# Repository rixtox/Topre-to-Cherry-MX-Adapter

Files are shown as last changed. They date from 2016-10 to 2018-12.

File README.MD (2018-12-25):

# Topre to Cherry MX Adapter

> [][2]
HHKB Topre to Cherry MX Adapters by [Naiwei Zheng][3] is licensed under a [Creative Commons Attribution-NonCommercial-ShareAlike 4.0 International License][2].

This is a 3D printable model made with SolidWorks that works to replace the cylindrical sliders (or plunger) of Topre switches on HHKB. The idea was first come up with Matt3o, and then the NovaTouch implemented the design in their products. For more information you can read [my blog about this project.][4]

This model made several improvements to [Matt3o's beta STL design model][5]. The base stands were made thinner to prevent stucking the rubber dome while pressed. The base was made exactly the same as the original Topre's to retain the touch feeling.

If you want to support this work, you can buy from my [Shapeways shop][6] where I make 10% fixed profits, or you can donate to [my PayPal][7] or BitCoin wallet: 14VSt78bfgMx9pWXV9qbMMsxter7KYHCRd. However you are always welcome to print and use this work for personal use without paying me.

## Compatibility Notes

Since different manufactures may have different specifications in their keycap dimensions, current design may not fit perfectly on every keycap out there. Hence hereby you are welcome to provide any compatibility results to me.

* [The Amazing Chocolatier Custom SA Keycap Set][8] - **Compatible**
* [87U with PuLSE SA Keycap Set][9] - **Wobbly 2.25u** ([Issue #1][10])

## Image Previews

### 1u Standard Adapter

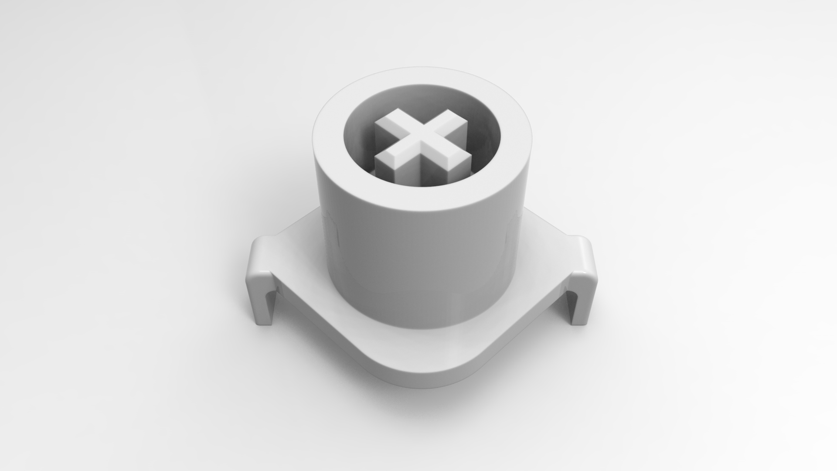
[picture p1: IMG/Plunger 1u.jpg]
Plunger 1u


### 2.25u Left Shift & Enter Adapter

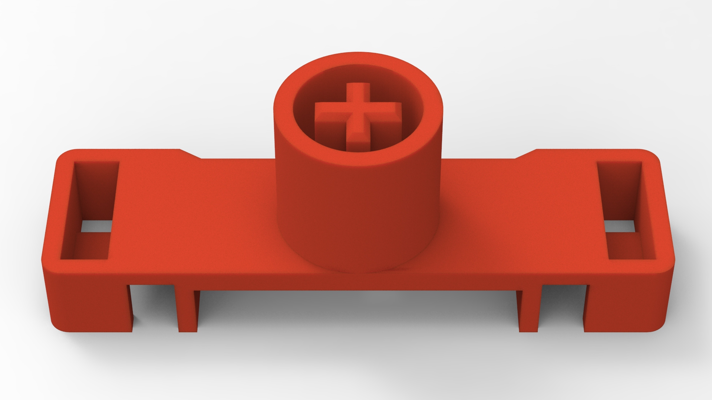
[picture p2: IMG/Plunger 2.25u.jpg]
Plunger 2.25u


### 6.25u MX Spacebar Stabilizer Adapters

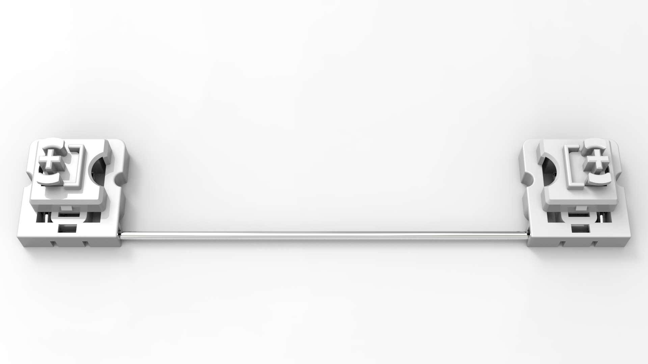
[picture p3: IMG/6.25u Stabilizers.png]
6.25u Spacebar Stabilizers


### 6u MX Spacebar Stabilizer Adapters

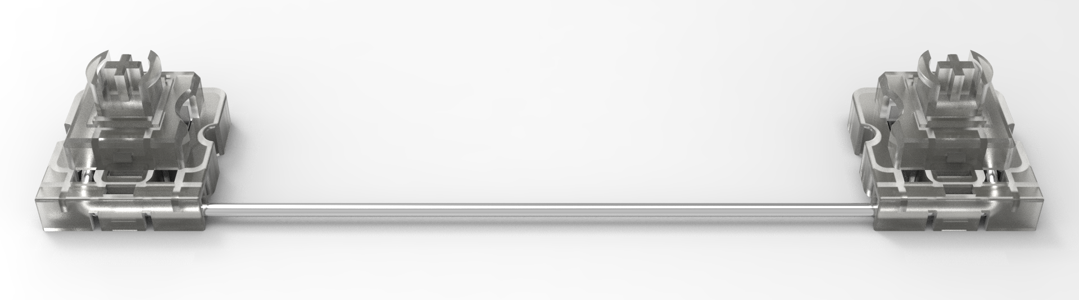
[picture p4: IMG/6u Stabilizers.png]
6u Spacebar Stabilizers


### 6u Topre Spacebar

In case you couldn't buy a PBT Topre 6u spacebar, I also made a model
for you to 3D print it.

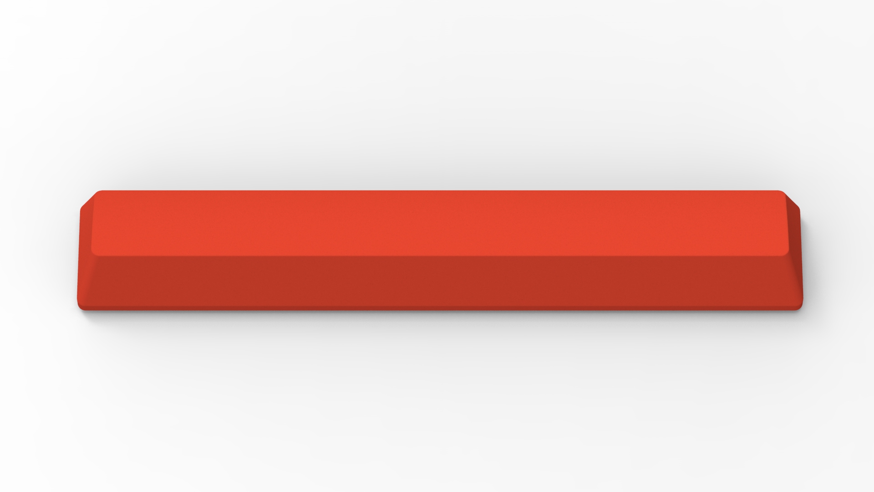
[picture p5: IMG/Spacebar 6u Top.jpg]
Spacebar 6u Top


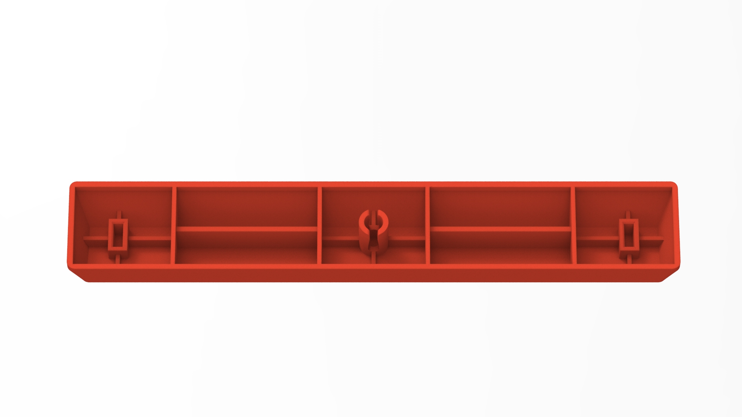
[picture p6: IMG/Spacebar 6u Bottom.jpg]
Spacebar 6u Bottom


## File Structure

    .
    ├── README.MD               # This document
    ├── ASM/                    # Assembly files
    ├── IMG/                    # Preview images
    ├── PRT/                    # Parts files
    └── STL/                    # 3D printable files

[1]: https://i.creativecommons.org/l/by-nc-sa/4.0/88x31.png
[2]: https://creativecommons.org/licenses/by-nc-sa/4.0/
[3]: https://github.com/rixtox/Topre-to-Cherry-MX-Adapter
[4]: https://rix.li/topre-to-cherry-mx-adapter/
[5]: http://matt3o.com/topre-to-cherry-mx-adapter/
[6]: https://www.shapeways.com/shops/axiom-1
[7]: https://paypal.me/naiwei
[8]: https://www.massdrop.com/buy/24022
[9]: https://www.massdrop.com/buy/pulse-sa-keycap-set
[10]: https://github.com/rixtox/Topre-to-Cherry-MX-Adapter/issues/1

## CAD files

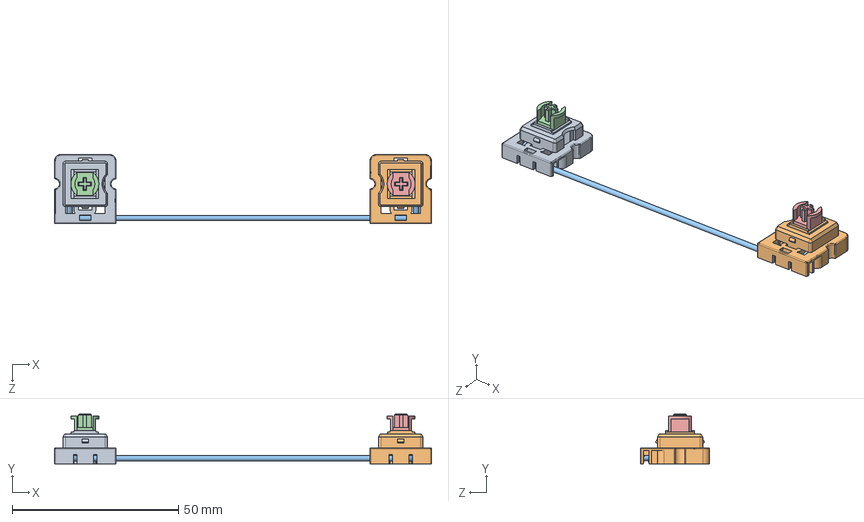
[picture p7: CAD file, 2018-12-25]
ASM/6u Stabilizers.SLDASM
113.5 x 14.9 x 20.9 mm
6u Stabilizer Housing Left
6u Stabilizer Housing Right
Stabilizer Wire
6u Stabilizer Plunger Left rev.2
6u Stabilizer Plunger Right rev.2

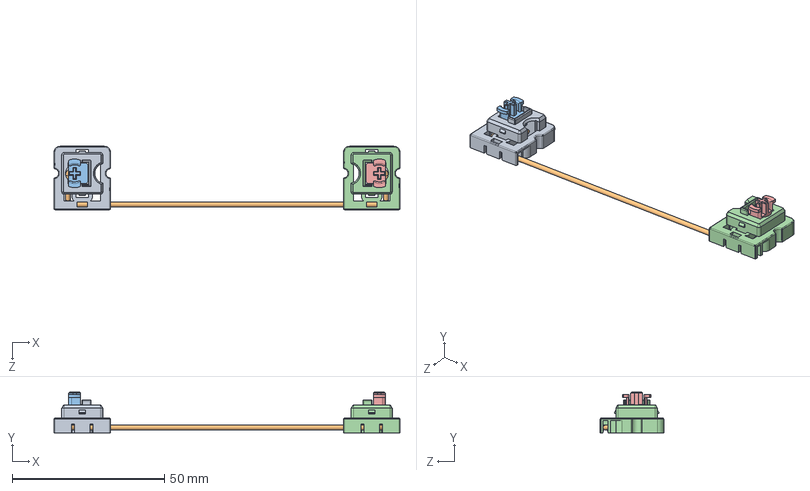
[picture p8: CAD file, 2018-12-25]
ASM/Stabilizers.SLDASM
113.5 x 13.3 x 20.9 mm
Stabilizer Housing Left
Stabilizer Wire
Stabilizer Plunger Left
Stabilizer Housing Right
Stabilizer Plunger Right

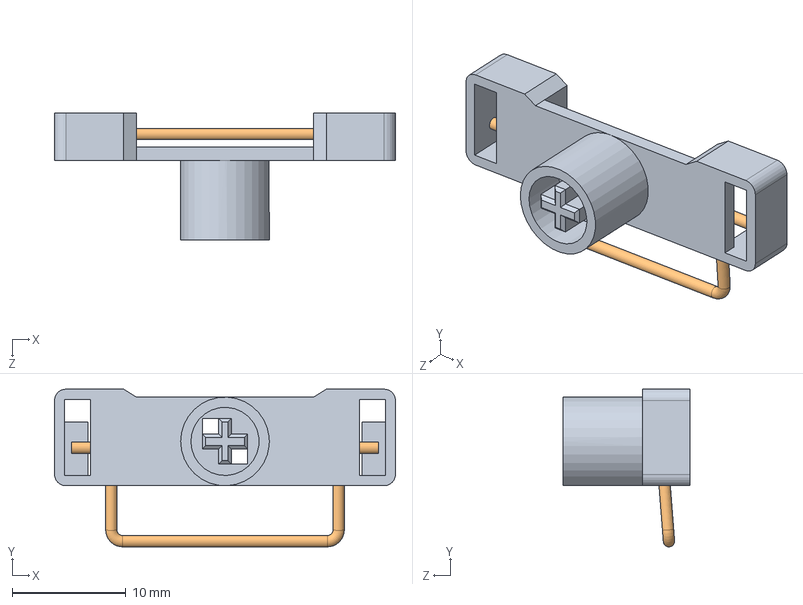
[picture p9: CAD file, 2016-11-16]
ASM/Plunger 2.25x.SLDASM
30.0 x 13.9 x 11.2 mm
Plunger 2.25x
Plunger String 2.25x

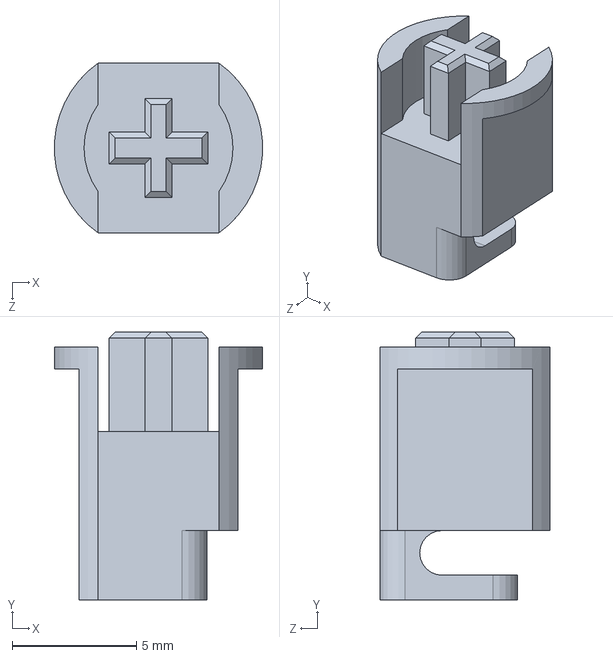
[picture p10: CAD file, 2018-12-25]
PRT/6u Stabilizer Plunger Right rev.2.SLDPRT
8.38 x 10.8 x 6.85 mm

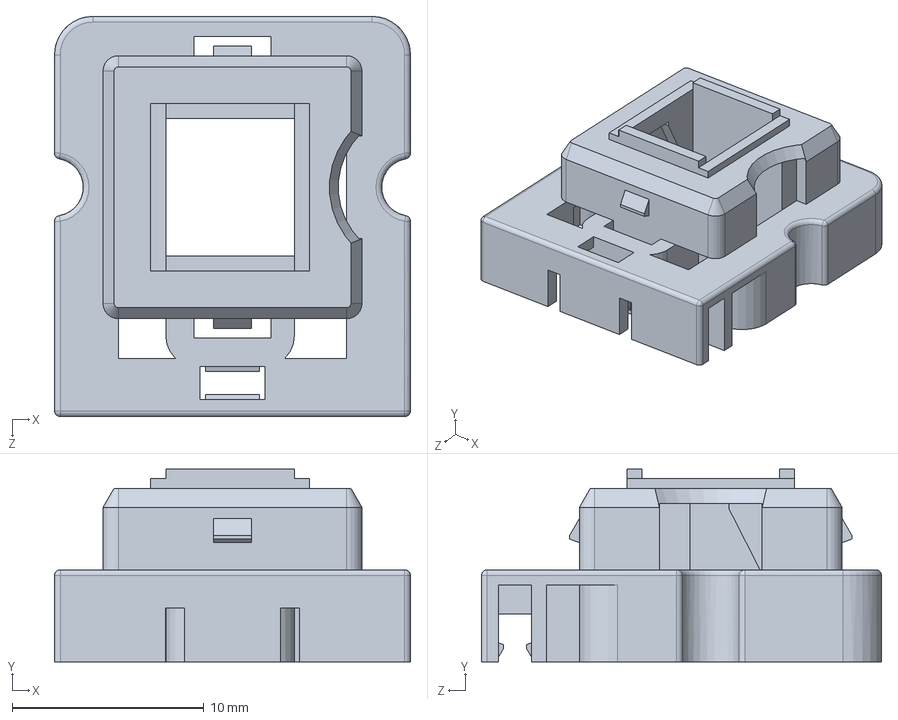
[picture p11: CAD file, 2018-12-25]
PRT/6u Stabilizer Housing Left.SLDPRT
18.5 x 10.1 x 20.9 mm

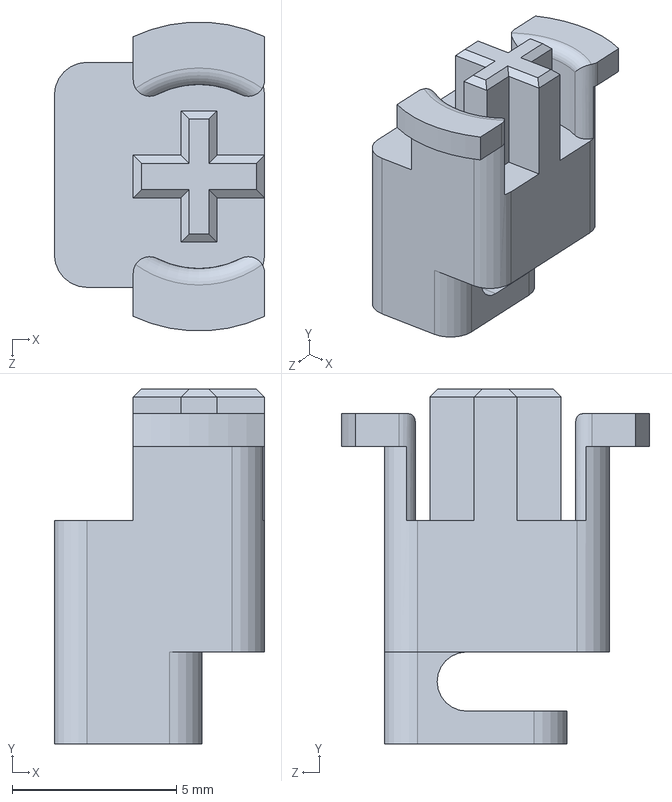
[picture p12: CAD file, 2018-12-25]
PRT/6u Stabilizer Plunger Right.SLDPRT
6.40 x 10.8 x 9.38 mm

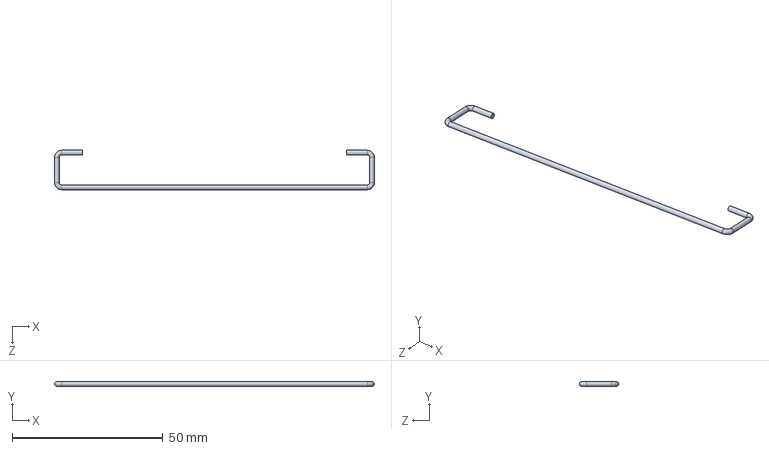
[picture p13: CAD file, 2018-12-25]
PRT/Stabilizer Wire.SLDPRT
106.0 x 1.60 x 13.1 mm

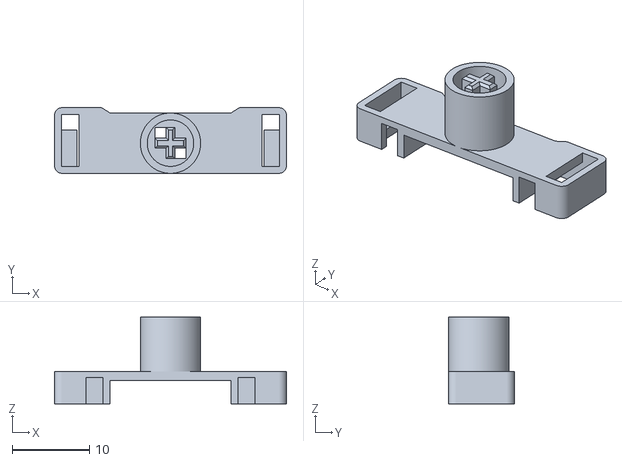
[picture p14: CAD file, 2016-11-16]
STL/Plunger 2.25x.STL
30.0 x 8.50 x 11.2

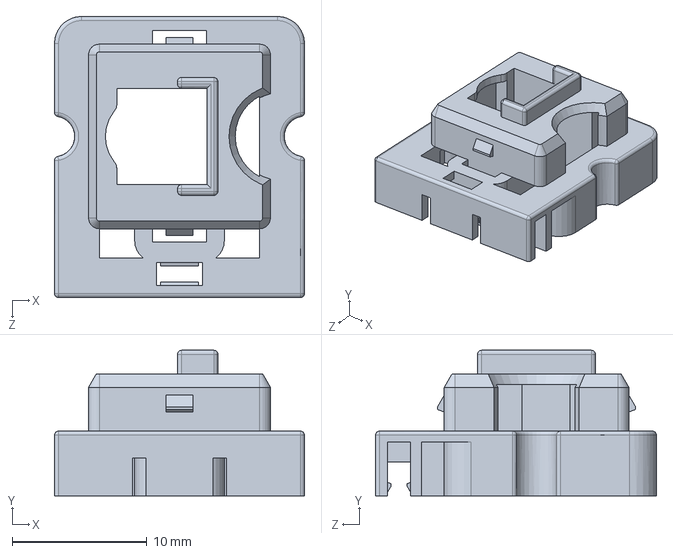
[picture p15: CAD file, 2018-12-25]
PRT/Stabilizer Housing Left.SLDPRT
18.5 x 10.8 x 20.9 mm

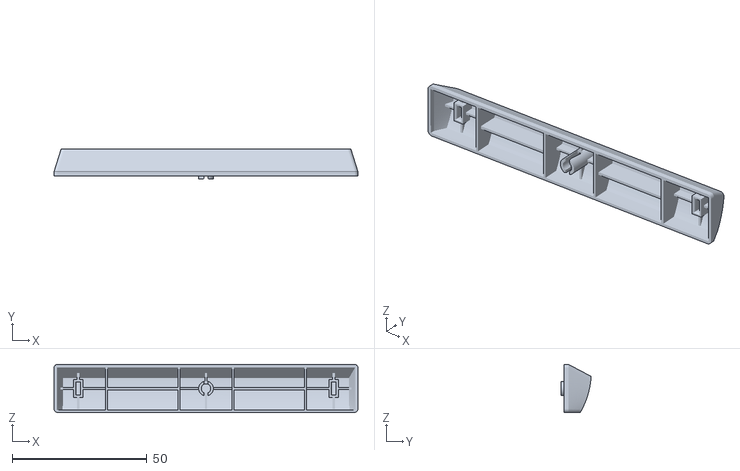
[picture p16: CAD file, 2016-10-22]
STL/Spacebar 6x.STL
113.0 x 11.3 x 18.0

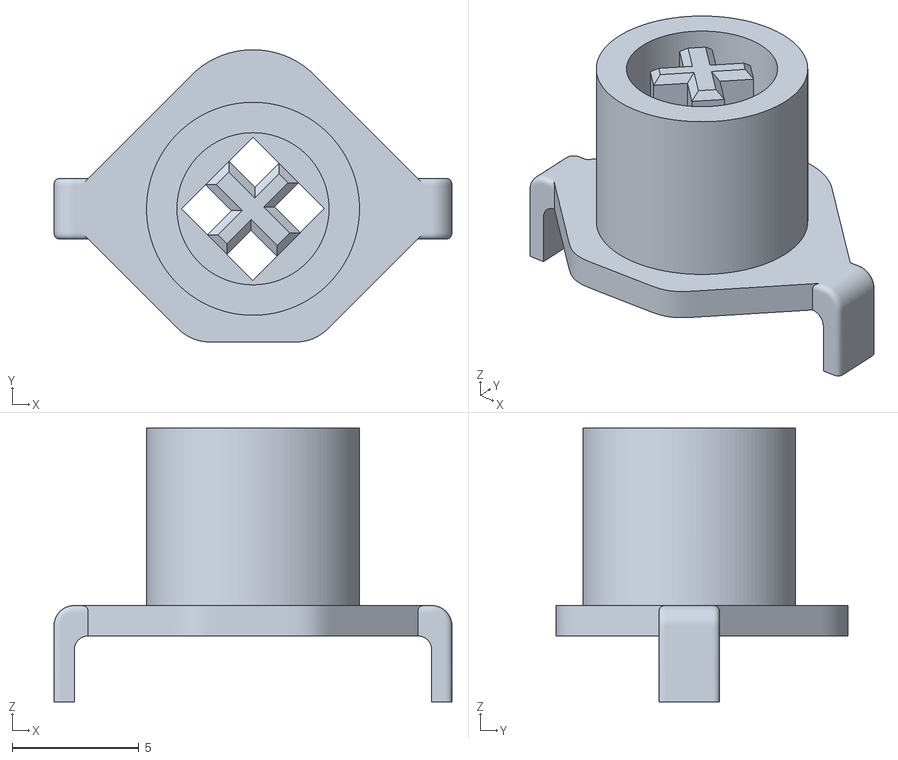
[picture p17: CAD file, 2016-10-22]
STL/Plunger 1x.STL
15.7 x 11.5 x 10.8

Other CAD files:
STL/6u Stabilizer Plunger Left rev.2.STL
STL/6u Stabilizer Plunger Right rev.2.STL
STL/Stabilizer Plunger Left.STL
STL/Stabilizer Plunger Right.STL
PRT/Stabilizer Plunger Left.SLDPRT
PRT/6u Stabilizer Plunger Left.SLDPRT
PRT/6u Stabilizer Plunger Left rev.2.SLDPRT
PRT/6u Stabilizer Housing Right.SLDPRT
PRT/Plunger 1x.SLDPRT
PRT/Plunger 2.25x.SLDPRT
PRT/Plunger String 2.25x.SLDPRT
PRT/Spacebar 6x.SLDPRT
PRT/Stabilizer Housing Right.SLDPRT
PRT/Stabilizer Plunger Right.SLDPRT
STL/Plunger String 2.25x.STL

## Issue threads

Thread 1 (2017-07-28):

Stabs are too short for SA profile keys w/ Realforce 87U

connor4312, 2017-07-28:
I got four stabilizer from Shapeways for my 87U with PuLSE SA keycaps. Unfortunately it seems the stems are too short. When placing the keycaps from the top, they're wobbly and come off easily. With enough force they "stick", but go down too far and actuation is prevented. I tried taking apart the board and pushing the caps on the stabilizers from the bottom, but the same actuation problem occurred.

rixtox, 2017-07-28:
Do you mean the plungers are easy to come off from the keycap stems? Did you follow the installation instructions on the stabilizer's Shapeways page? The order of the procedures are important.

connor4312, 2017-07-28:
Sorry, yes, this is for the 2.25U plungers, not the spacebar stabilizers. I followed the instructions insofar as getting them printed in frosted ultra detail. For the other keys I used [1upkeyboard's topre-mx sliders](https://1upkeyboards.com/topre-mx-sliders.html) which were about 1-2mm taller than these plungers and fit fine.

rixtox, 2017-07-28:
Oh I see. I use the word "stabilizers" mainly to refer the pair of space bar stabilizers. If you are talking about the 2.25u adapters, yes things may get complicated. The adapter behaves differently on 2.25u keycaps from different manufactures. As their stem diameters and the tightness of the stems varies from 1u to 2.25u, and each manufacture has its own specification, and usually not publicly available. I only have access and measured some keycaps I had available, so what I did was to make the inner diameter of the adapter's stem a bit wider to ensure most keycaps can fit into the hole, but it might lead to some keycaps a bit wobbly. A dirty fix of the problem is to stuck a piece of thin paper into the adapter plunger hole, making the inner diameter smaller. The best solution is to measure the diameter of your keycap's stem with digital vernier caliper. Then change the inner diameter in the CAD and reprint it to fit your need.

connor4312, 2017-07-28:
Ok, thanks for the advice 😄 Just wanted to make sure I wasn't doing something wrong. I might try making 87U versions if I ever get some free time, and submit a PR for the updated models if it ends up working out.

For the moment though it might make sense to toss a note in the readme that the plungers are incompatible with the 87U keyboards.

rixtox, 2017-07-28:
You are more than welcome to submit a PR. Thanks for helping to improve this project! README was just updated.

Closed 2017-07-28.

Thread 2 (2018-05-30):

Is it compatible with GMK's 6u centered spacebar?

yzlnew, 2018-05-30:
Many GMK's core set contains a 6u centered spacebar like [this](https://www.massdrop.com/buy/massdrop-x-zambumon-gmk-nautilus-custom-keycap-set).

rixtox, 2018-05-31:
Current design is incompatible with any 6u spacebar.
However I do have an on going design for GMK's 6u centered spacebar.
It's been a long run and I've been constantly distracted from this project by other matters.
I'm traveling right now and will finish it up when I get back home in early June.

Sorry for anyone waiting for the update. I will send out some free samples for people waiting on this for months.

d-yoshi, 2018-07-28:
That is what I really want.
I can't wait!

d-yoshi, 2018-12-25:
Why was this Issue closed?
Was this released somewhere?

yzlnew, 2018-12-25:
@d-yoshi It seems this repo is deprecated.

rixtox, 2018-12-26:
It's been done now.

yzlnew, 2018-12-26:
Shout out to @rixtox .
Now closed officially. Happy modding HHKB 😊

Closed 2018-12-25.

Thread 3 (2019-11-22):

Keystem too tight

ApolloBian, 2019-11-22:
I tried your solution and overall I'm very satisfied with the end result.
However I do notice that the keystem is too tight for many keycaps.
I inspected the file and get the noticed the specification as below:
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
which does not conform to the standard cherry mx keystem size [https://www.cherrymx.de/en/dev.html](cherry mx dev page):
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

rixtox, 2019-11-22:
I didn't know such public schematic exists!
I measured those values manually so they may differ from the standard.
I will update the models so they use the official values.

Thanks for the info!

rixtox, 2019-11-22:
Do you think something like this would work better?
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

ApolloBian, 2019-11-23:
Hi @rixtox , thanks for the timely reply! IMO 1.15mm could be a better way to go, given you can print with 0.05mm accuracy printers. Maybe include 2 versions (1.15 and 1.10) is a good idea.

ApolloBian, 2019-11-27:
May I ask you to update the modified models in your free time?

rixtox, 2019-11-27:
> May I ask you to update the modified models in your free time?

I'm not sure making two versions of every adapters just for a 0.05mm clarance is a good idea. Especially it would cause a lot of confusion to people.

I think we should actually print them out and conduct an evaluation before choosing one.

ApolloBian, 2019-11-27:
Good point. I'm actually planning to print the stems for a new keyboard. If you can send me the modified versions I'll be happy to help test it and give more feedback. (I'm not capable of modifying the models though)

ApolloBian, 2019-12-08:
Hi @rixtox . I tried the 1.1mm version and it is very good. Also I'd like to point out that the diameter for the cylinder should be 8.2mm, and width of the feet should be 2.3mm and I recommend to update it, because the original model is too tight and hard to press and I have to sand it manually
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

driph, 2021-07-07:
Heya, has the repo been updated with the files with the accurate stems?

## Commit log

2016-08-14 Add Plunger 2.25x
    [Plunger 1x.SLDPRT, Plunger 1x.STL, Plunger 2.25x.SLDASM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]
2016-10-22 Add spacebar 6x
    [Spacebar 6x.SLDPRT, Spacebar 6x.STL]
2016-11-16 Updated 2.25
    [Plunger 2.25x.SLDASM, Plunger 2.25x.SLDPRT, Plunger 2.25x.STL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]
2017-04-09 Spacebar stabilizers rev.0
    [Stabilizer Housing Left.SLDPRT, Stabilizer Housing Right.SLDPRT, Stabilizer Plunger Left.SLDPRT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]
2017-04-09 Spacebar stabilizers rev.1
    [Stabilizer Housing Left.SLDPRT, Stabilizer Housing Right.SLDPRT, Stabilizer Plunger Left.SLDPRT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]
2017-04-15 minor changes to spacebar stabilizers
    [Stabilizer Housing Left.SLDPRT, Stabilizer Housing Right.SLDPRT, Stabilizer Plunger Left.SLDPRT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]
2018-12-25 Add 6u spacebar stabilizers
    [6u Stabilizer Housing Left.SLDPRT, 6u Stabilizer Housing Right.SLDPRT, 6u Stabilizer Plunger Left rev.2.SLDPRT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]

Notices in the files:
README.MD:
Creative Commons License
